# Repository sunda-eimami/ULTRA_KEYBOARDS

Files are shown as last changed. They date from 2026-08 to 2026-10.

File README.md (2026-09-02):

# first — 44キー分割無線キーボード (Ergogen → KiCad)

片側 22 キー（メイン 3行×6列 ＋ 親指 4キー）、Kailh Choc v2 ホットスワップ、
**Seeed XIAO nRF52840 Plus** の分割無線キーボード。`config.yaml` から Ergogen で
左右 2 枚の KiCad PCB を自動生成し、Freerouting による自動配線・DRC・ガーバー生成まで済んでいます。

| 全 44 キー配置 | 配線済み PCB (左/右) |
| --- | --- |
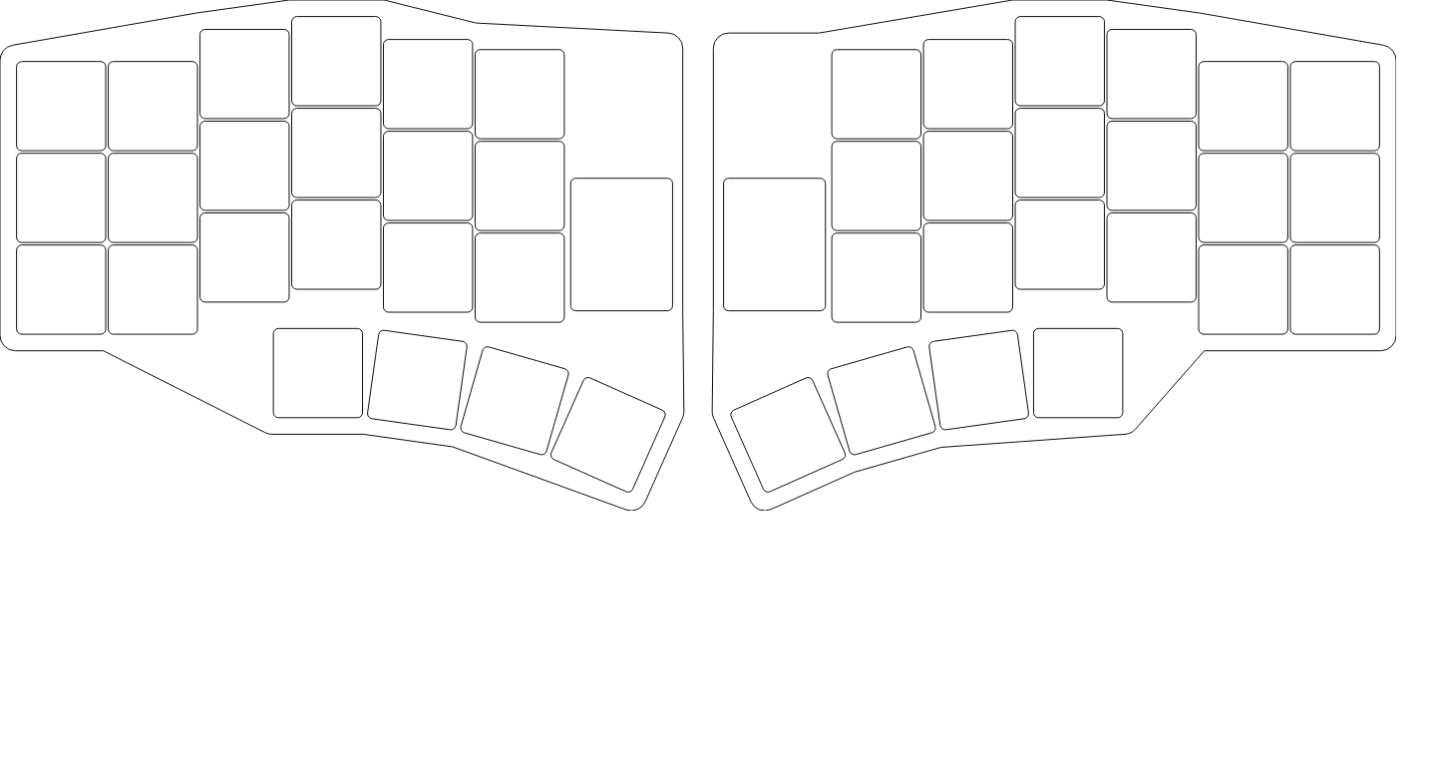
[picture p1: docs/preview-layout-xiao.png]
layout
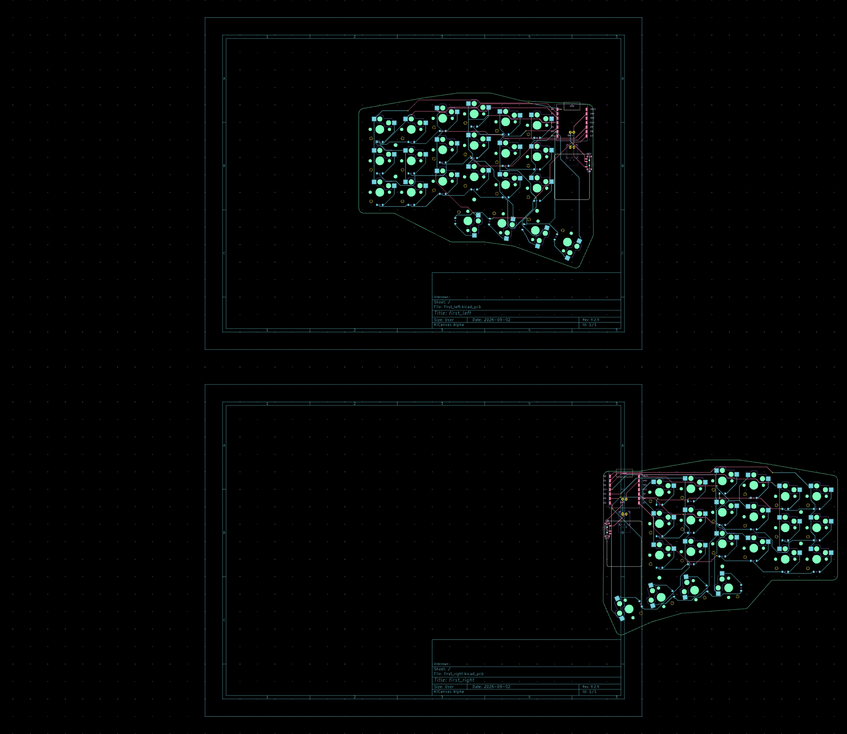
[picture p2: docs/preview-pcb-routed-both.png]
routed
|  |  |

## 状態 (2026-09-02)

- `kicad/first_left.kicad_pcb` / `kicad/first_right.kicad_pcb` — **配線済み・DRC 違反 0・未配線 0**
- `gerbers/first_left.zip` / `gerbers/first_right.zip` — **発注用ガーバー**（JLCPCB 等にそのままアップロード可）

## 使い方

```sh
npm install          # ergogen をローカルにインストール
npm run build        # = ergogen . --clean   → output/ に未配線 PCB を再生成
npm run build:svg    # 外形 SVG も出力
```

> **注意**: `output/` はビルドのたびに完全に上書きされます。配線済みデータは `kicad/`、
> 発注データは `gerbers/` にあり、これらはビルドでは消えません。config を変更したら
> 「`npm run build` → `output/pcbs/*.kicad_pcb` を `kicad/` にコピー → 再ルーティング」が必要です。

## ディレクトリ構成

```
.
├── config.yaml              Ergogen 設定 = 回路の一次ソース (キー配置・外形・ネット定義)
├── footprints/
│   ├── ceoloide/            ceoloide/ergogen-footprints (Choc, ダイオード, JST, 電源SW 等) ※CC BY-NC-SA 4.0
│   └── local/mcu_xiao_nrf52840_plus.js   XIAO nRF52840 Plus (Seeed 公式 KiCad データの座標から作成)
├── output/                  Ergogen 生成物 (未配線。ビルドごとに上書き)
├── kicad/                   配線済み PCB (Freerouting + 手修正、DRC クリーン)
├── gerbers/                 発注用ガーバー zip
└── docs/                    プレビュー画像
```

## 設計メモ

- **配列**: 列は外側から `outer, pinky, ring, middle, index, inner`、行は下から `bottom, home, top`。
  Columnar stagger は pinky 基準で ring +6.3 / middle +8.8 / index +4.3 / inner +2.3 mm。
  親指 4 キーは `rotate: -90`、半径 140mm の円弧上に 8° ピッチで扇状配置。
- **左右別基板**: XIAO は USB・リセットボタンが上面にあるためリバーシブル化できず、
  左手用 (`first_left`) と右手用 (`first_right`) を別々に生成・配線しています。
- **実装面**: スイッチソケット・ダイオード = 裏面 / XIAO・JST・電源スイッチ = 表面。
  XIAO は castellated パッドで表面に直付け。バッテリー (502030) は MCU 下の「ベイ」裏面。
- **ピン割当 (ZMK: `&xiao_d n`)**
  | 用途 | ピン |
  |---|---|
  | 列 outer→inner | D0 D1 D2 D3 D4 D5 |
  | 親指 t1→t4 | D2 D3 D4 D5 (列を流用) |
  | 行 top / home / bottom / thumb | D9 / D8 / D7 / D6 |
  | 電源 | JST(BAT_P) → 電源SW → VBAT (モジュール裏パッド、基板のスルーホール経由で半田付け) |
  | リセット | XIAO 本体ボタン (1回=リセット、素早く2回=ブートローダ) |
  | 空き | D10 (+ Plus 裏面の D11〜D19) |
- **ダイオード**: 1N4148W (SOD-123)、col2row。帯マーク (カソード) が行ネット側。
- **マウントホール**: M2 NPTH ×4/枚。

## 発注 (JLCPCB の例)

1. [jlcpcb.com](https://jlcpcb.com) で `gerbers/first_left.zip` をアップロード → 2層 / 1.6mm / 1oz / HASL でそのまま注文 (最低5枚)
2. `first_right.zip` も同様に注文 (別設計扱い)
3. 部品: Choc v2 スイッチ×44、Choc ソケット×44、1N4148W×44+予備、XIAO nRF52840 Plus×2、
   JST PH 2P×2、電源SW (Alps SSSS811101)×2、502030 LiPo×2

## メンテナンスの流れ

回路図ファイル (.kicad_sch) は存在しません。**`config.yaml` が回路図に相当する一次ソース**で、
接続定義 (from/to) はすべてそこに書かれています。回路を変更するときは config を編集して再生成し、
Freerouting で再ルーティングします (このリポジトリの履歴と配線図ドキュメントを参照)。

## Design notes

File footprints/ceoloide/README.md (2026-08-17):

# @ceoloide's ergogen PCB footprints

> [!WARNING]
> These footprints have only been partially tested and are still under active development. Use them at your own risk.

1. [How to use these footprints in Ergogen](#how-to-use-these-footprints-in-ergogen)
1. [Installation](#installation)
    1. [How to add the footprints as a local git submodule](#how-to-add-the-footprints-as-a-local-git-submodule)
    1. [How to add the footprints as a GitHub Codespaces git submodule](#how-to-add-the-footprints-as-a-github-codespaces-git-submodule)
    1. [How to use the footprints in your ergogen config](#how-to-use-the-footprints-in-your-ergogen-config)
    1. [How to clone your ergogen repo](#how-to-clone-your-ergogen-repo)
    1. [How to update footprints dependencies](#how-to-update-footprints-dependencies)
    1. [How to remove footprints dependencies](#how-to-remove-footprints-dependencies)
1. [How to design or modify ergogen footprints](#how-to-design-or-modify-ergogen-footprints)
1. [Licenses and recognition](#licenses-and-recognition)

## How to use these footprints in Ergogen

> [!WARNING]
> These footprints have been upgraded to KiCad 8 and are only compatible with Ergogen v4.1.0 and above. Make sure to set the `template: kicad8` option in each PCB definition:

```yaml
meta:
  engine: 4.1.0 # Min Ergogen version for KiCad 8 footprints
[...]
pcbs:
  main_pcb:
    template: kicad8 # Required, since footprints are KiCad 8 only
    outlines:
      [...]
    footprints:
      [...]
```

> [!NOTE]
> You can directly use these custom footprints in the experimental GUI at [ergogen.ceoloide.com](https://ergogen.ceoloide.com). Just refer to them as `ceoloide/[footprint_filename]`, for example: `ceoloide/switch_mx`.

Using custom footprints with a local Ergogen setup is relatively straightforward. You can follow the steps outlined in [this amazing guide](https://flatfootfox.com/ergogen-part4-footprints-cases/) if you want an easy tutorial.

If you are already comfortable running Ergogen locally, you just need to:

1. rename your Ergogen YAML file to `config.yaml`,
1. create a `footprints` folder alongside it
1. clone this repo into the `footprints` folder using a folder name of your choice (see instructions below)
1. now run Ergogen by passing a folder instead of a YAML file, for example `ergogen .`

## Installation

### How to add the footprints as a local git submodule

> [!WARNING]
> If you are using GitHub Codespaces, skip the following instructions and go to the next section.

If you have git setup on your local environment with SSH credentials, you can add the library as a
git submodule. To use custom footprint, ergogen requires them to be located under a folder named
`footprints` placed alongside a `config.yaml` file containing the board definition.

Assuming the above files are located at `./ergogen` from the git folder root, then you can use this
command to add the footprints into a `ceoloide` folder in the right location:

```bash
git submodule add git@github.com:ceoloide/ergogen-footprints.git ergogen/footprints/ceoloide
```

Note that you can customize `ceoloide` to be whatever name you choose. Just make sure to refer to the custom
name in your YAML file.

### How to add the footprints as a GitHub Codespaces git submodule

Due to the limitations on how GitHub Codespaces handle submodules, use this command instead of the one above:

```bash
git submodule add https://github.com/ceoloide/ergogen-footprints.git ergogen/footprints/ceoloide
```

### How to use the footprints in your ergogen config

Assuming you used `ergogen/footprints/ceoloide` as the destination folder for the submodule, you will be able
to refer to any footprint contained in that folder as `ceoloide/[footprint_filename]`, which would look something like this:

```yaml
meta:
  engine: 4.1.0 # Min Ergogen version for KiCad 8 footprints
[...]
pcbs:
  your_keyboard:
    template: kicad8 # Required, since footprints are KiCad 8 only
    outlines:
      [...]
    footprints:
      nice_nano:
        what: ceoloide/switch_mx
        [...]
```

### How to clone your ergogen repo

Users who clone your ergogen repo, must also include the submodule. So you should instruct them to clone with `--recursive` mode:

```bash
git clone --recursive git@github.com:your-user/your-keyboard.git
```

Alternative they can init and update the submodules in a repo that was already cloned without the `--recursive` argument:

```bash
git submodule update --init --recursive --remote
```

### How to update footprints dependencies

When you add a submodule, it won't automatically be updated, meaning that you will maintain files as long as you don't take specific actions. This is great to avoid having to deal with unforseen changes in the source.

Should you however want to update your footprint dependencies, you can run the following command:

```bash
git submodule update --recursive --remote
```

This will fetch and checkout the latest commits in the source repo and pull the files so they are available.

Be aware that you will need to commit the submodule update change, or it will revert with a subsequent pull. To do so you can run these commands:

```bash
# First add the updated submodule to the staged files
git add ergogen/footprints/ceoloide
# Then commit the staged files to persist the update
git commit -m "Update footprint submodule"
```

### How to remove footprints dependencies

If you do not longer need the footprint submodule and want to remove it from your repository, you can simply run this command:

```bash
git rm ergogen/footprints/ceoloide
```

This will update the `.gitmodules` file to remove the submodule reference and remove the submodule directory. Make sure to commit and push the
change for it to be persisted and propagated, or it will revert with a subsequent pull:

```bash
git commit -m "Remove footprint submodule"
```

## How to design or modify ergogen footprints

[@infused-kim](https://github.com/infused-kim) wrote a [guide on how to convert KiCad footprints to ergogen](https://www.notion.so/nilnil/Convert-Kicad-Footprint-to-Ergogen-8340ce87ad554c69af4e3f92bc9a0898?pvs=4), which
has been extensively used to create original ergogen footprints in this repository.

## Licenses

All original footprints and those copied from [@MrZealot](https://github.com/mrzealot), [@TildeWill](https://github.com/tildewill), and [@virginia2244](https://github.com/virginia2244) are licensed under [MIT License][mit]. I also extensively used and modified footprints created by [@infused-kim](https://github.com/infused-kim), which are licensed under [Creative Commons Attribution-NonCommercial-ShareAlike 4.0 International License][cc-by-nc-sa].

[][cc-by-nc-sa]

### What does the CC BY-NC-SA 4.0 license mean for your projects?

Because some footprints carry the **Creative Commons Attribution-NonCommercial-ShareAlike 4.0 (CC BY-NC-SA 4.0)** license, there are often questions about what you can and cannot do. 

> [!WARNING]
> I am not a lawyer, and this does not constitute formal legal advice. Below is my informed understanding on how this license practically applies to your keyboard projects.

#### 1. You CAN manufacture and sell the physical PCBs

Creative Commons licenses govern copyright, which protects *digital files and creative expression*, not functional physical hardware. Once you export Gerbers and send them to a fab (like JLCPCB or PCBWay), the resulting physical circuit board is a functional object and is no longer restricted by the CC copyright. You are legally free to commission these boards and sell the manufactured PCBs on your store.

* *Exception:* If a footprint contains separable artistic elements (like decorative silkscreen art), that art remains copyrighted even on the physical board. However, none of the footprints in this repository contain qualifying silkscreen art.

#### 2. You CANNOT sell or close-source the digital files

Your KiCad `.kicad_pcb` files, the generated Gerbers, and the Ergogen config files that use these footprints *are* subject to the copyright license. You cannot sell these digital files. If you share your modified design files or Gerbers with others, you **must** release them under the exact same CC BY-NC-SA 4.0 license and provide attribution.

#### 3. The Spirit of the License

While the license legally permits the sale of the physical, functional boards, applying a NonCommercial license in the open-source hardware community is often used to signal: *"Please don't manufacture and sell my designs for profit."* While you are legally allowed to sell the physical boards, please keep the community spirit in mind.

## Inspiration and recognition

All of the work I've done wouldn't have been possible without the inspiration or direct reference to the work done by:

- [@foostan](https://github.com/foostan) for the original [Corne keyboard](https://github.com/foostan/crkbd)
- [@flatfootfox](https://github.com/flatfootfox) for the [Ergogen v4 introductory articles](https://flatfootfox.com/ergogen-introduction/)
- [@infused-kim](https://github.com/infused-kim) for the [amazing work done with the footprints](https://github.com/infused-kim/kb_ergogen_fp) I ~stole from~ got inspired by
- [@MrZealot](https://github.com/mrzealot) / [@ergogen](https://github.com/ergogen) for the [amazing tool](https://github.com/ergogen/ergogen) and [amazing community](https://discord.gg/Tj2TUaUW)
- [@virginia2244](https://github.com/virginia2244) for the [incredible work on MCU footprints](https://github.com/Virginia2244/ergogen_footprints)
- [@benvallack](https://github.com/benvallack) for the [great video content on YouTube](https://www.youtube.com/watch?v=UKfeJrRIcxw) and getting me started on the Ergogen journey

[mit]: https://opensource.org/license/mit/
[cc-by-nc-sa]: http://creativecommons.org/licenses/by-nc-sa/4.0/
[cc-by-nc-sa-image]: https://licensebuttons.net/l/by-nc-sa/4.0/88x31.png

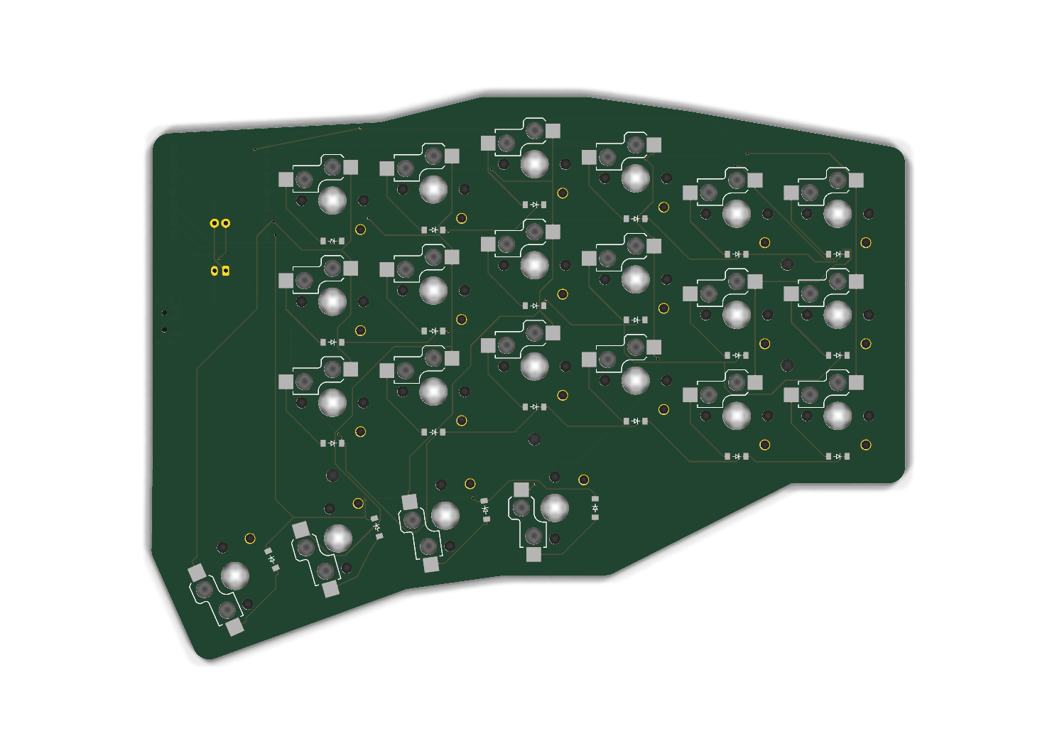
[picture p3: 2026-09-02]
docs/render3d-left-bottom.png

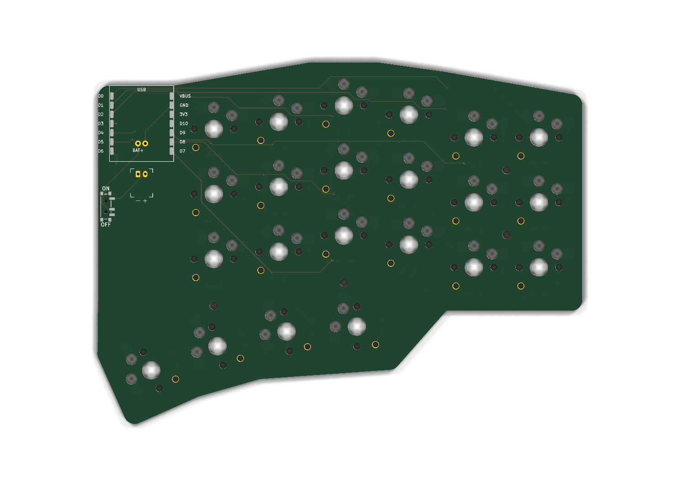
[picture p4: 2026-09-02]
docs/render3d-right-top.png

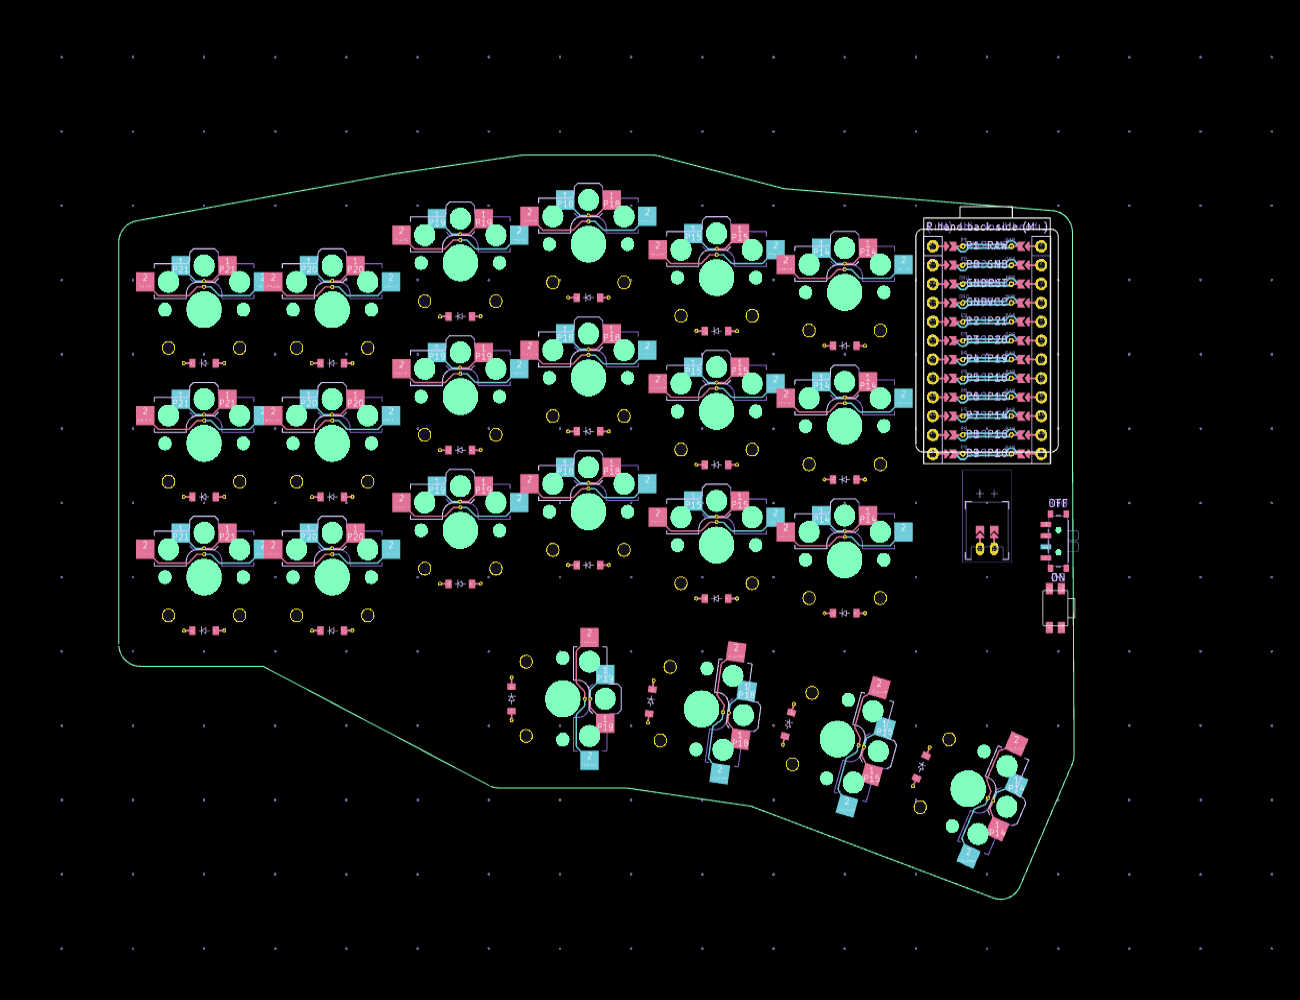
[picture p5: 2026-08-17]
docs/preview-pcb-kicanvas.png

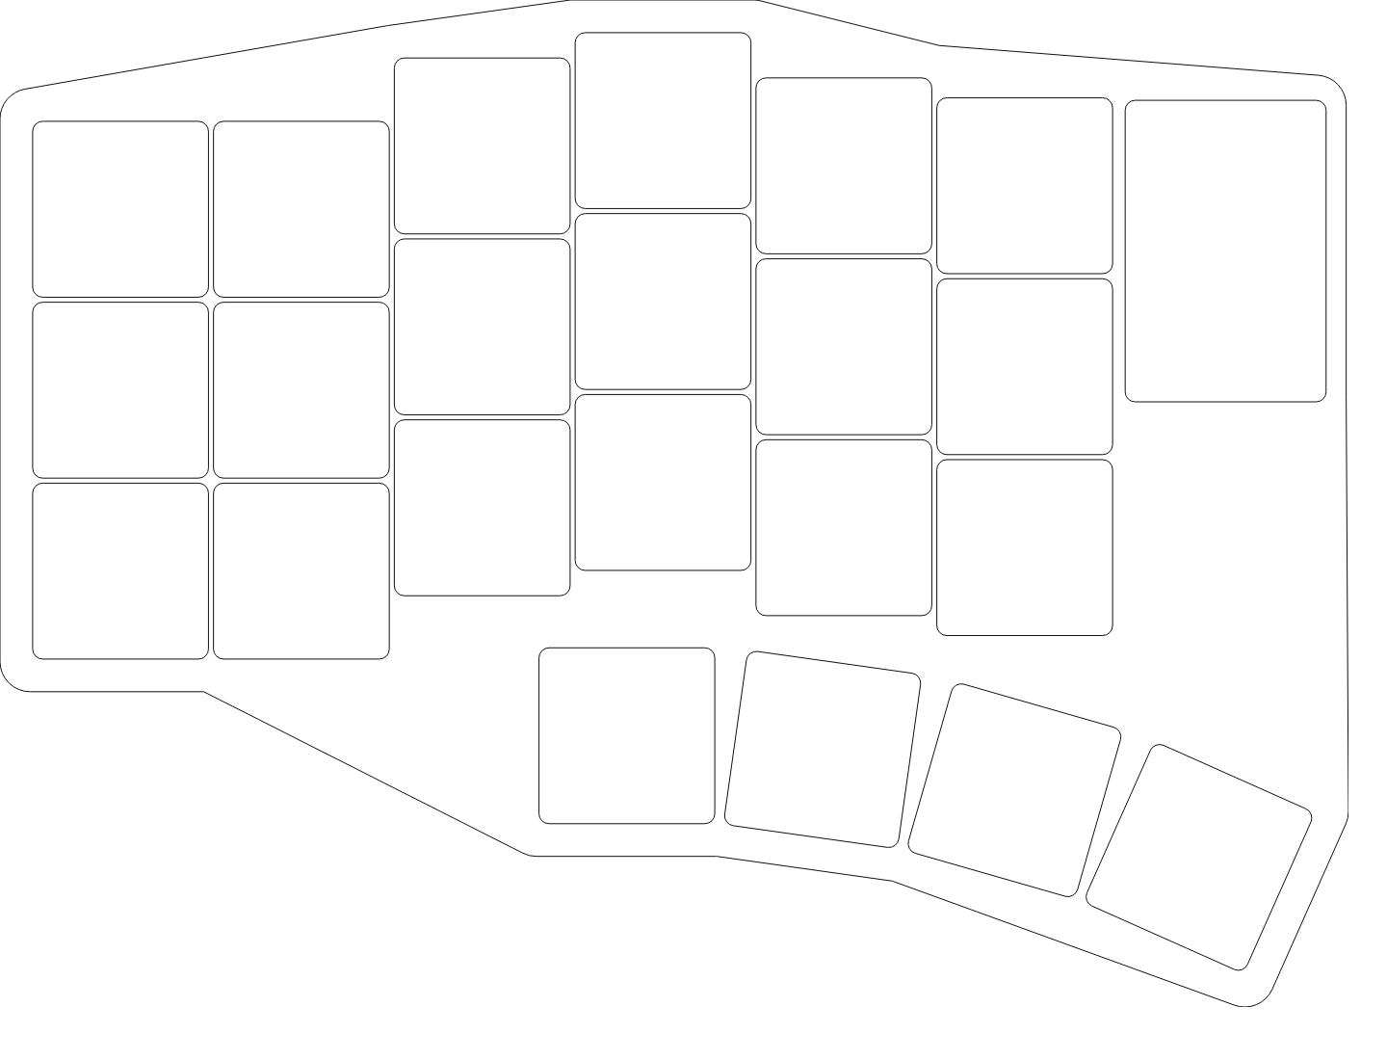
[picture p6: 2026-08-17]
docs/preview-left-outline.png

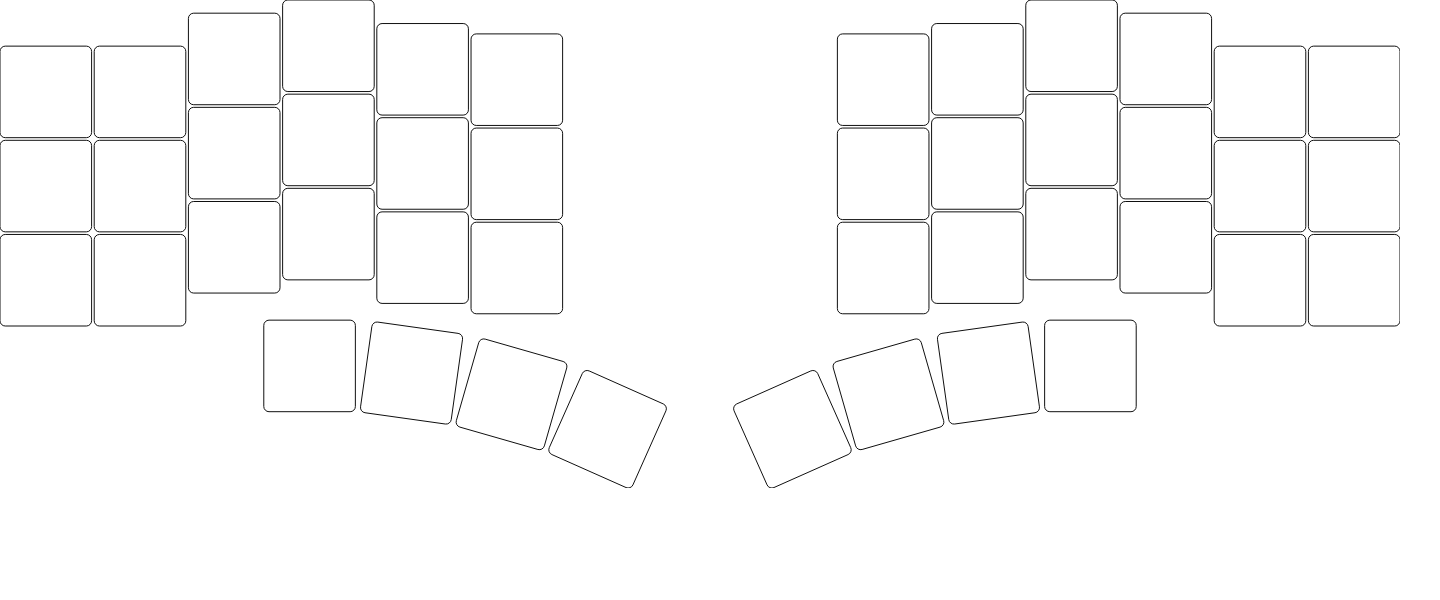
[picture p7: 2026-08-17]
docs/preview-layout-44keys.png

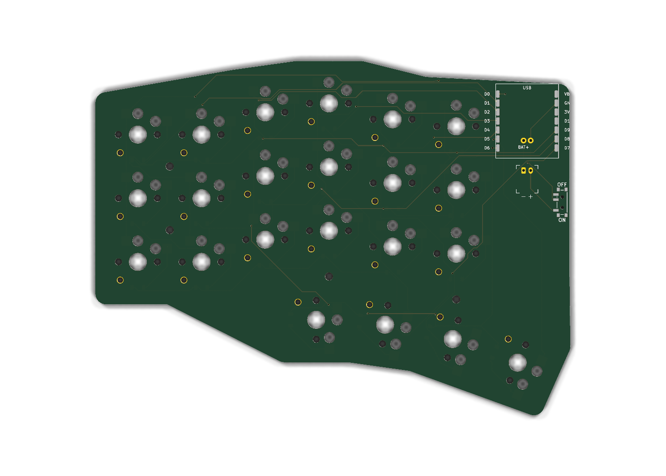
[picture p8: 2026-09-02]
docs/render3d-left-top.png

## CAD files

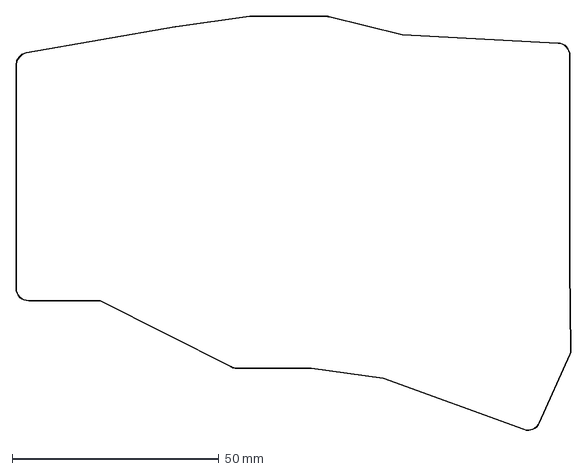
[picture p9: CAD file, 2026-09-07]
cad/board_left.dxf
134.2 x 100.5 mm

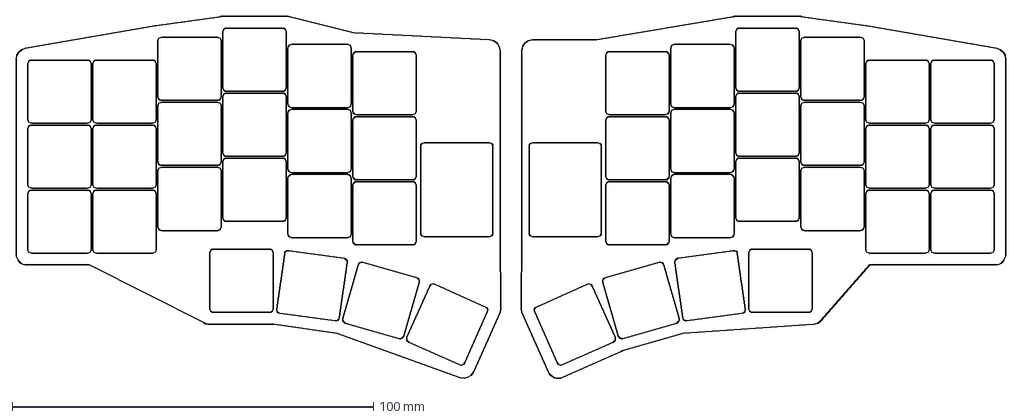
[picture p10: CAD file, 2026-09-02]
output/outlines/preview.dxf
274.0 x 100.5 mm

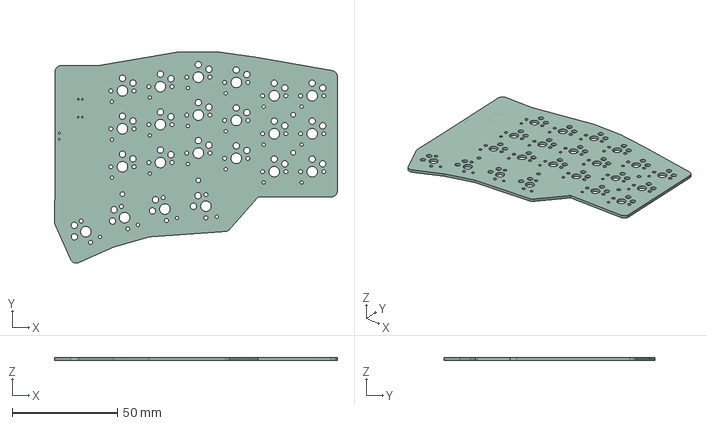
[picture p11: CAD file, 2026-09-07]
cad/first_right.step
134.2 x 100.2 x 1.51 mm

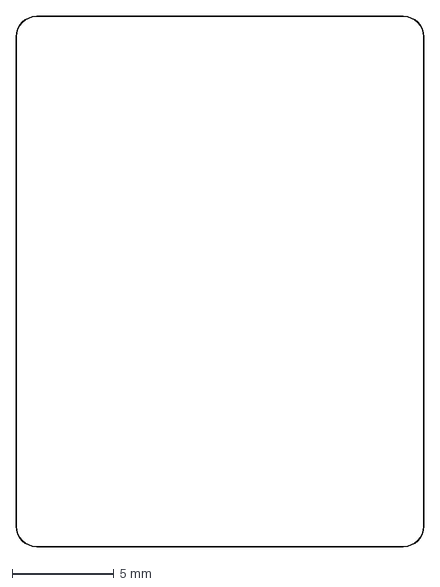
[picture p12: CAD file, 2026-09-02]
output/outlines/battery_right.dxf
20.0 x 26.0 mm

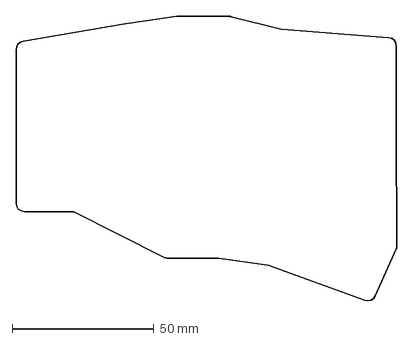
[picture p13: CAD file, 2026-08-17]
output/outlines/board.dxf
134.2 x 100.5 mm

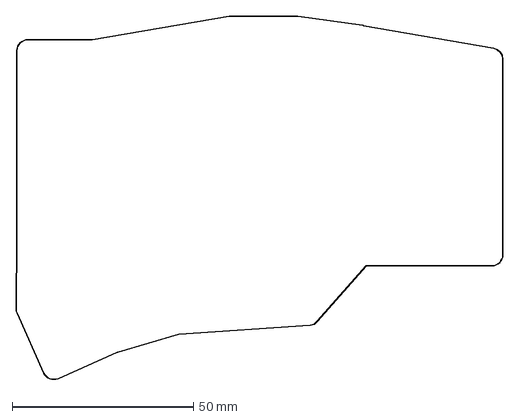
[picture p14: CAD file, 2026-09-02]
cad/board_right.dxf
134.2 x 100.3 mm

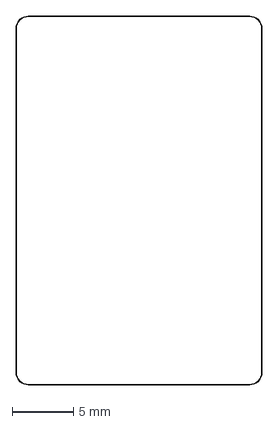
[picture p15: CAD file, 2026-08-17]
output/outlines/battery.dxf
20.0 x 30.0 mm

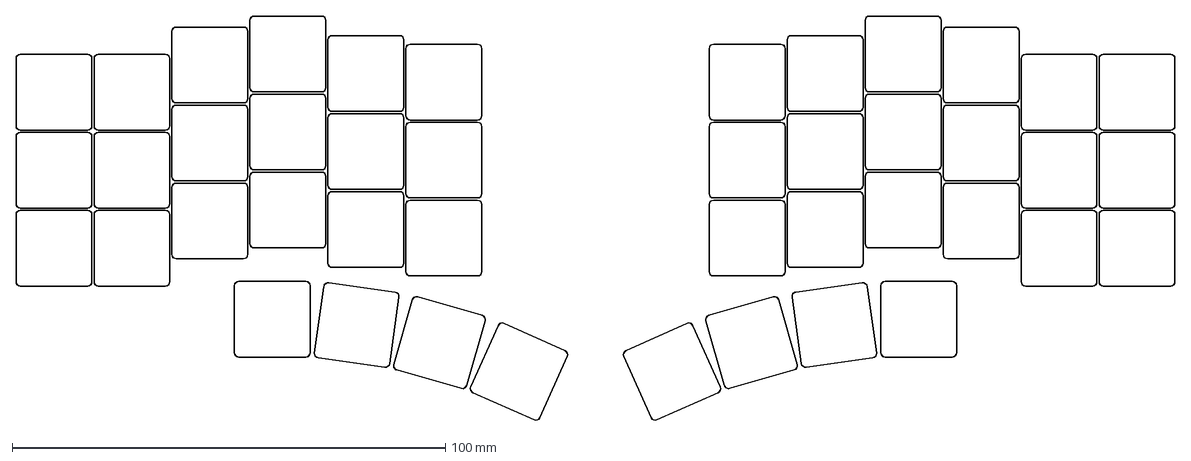
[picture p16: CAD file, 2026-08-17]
output/outlines/keys.dxf
267.5 x 93.4 mm

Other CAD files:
cad/first_left.step

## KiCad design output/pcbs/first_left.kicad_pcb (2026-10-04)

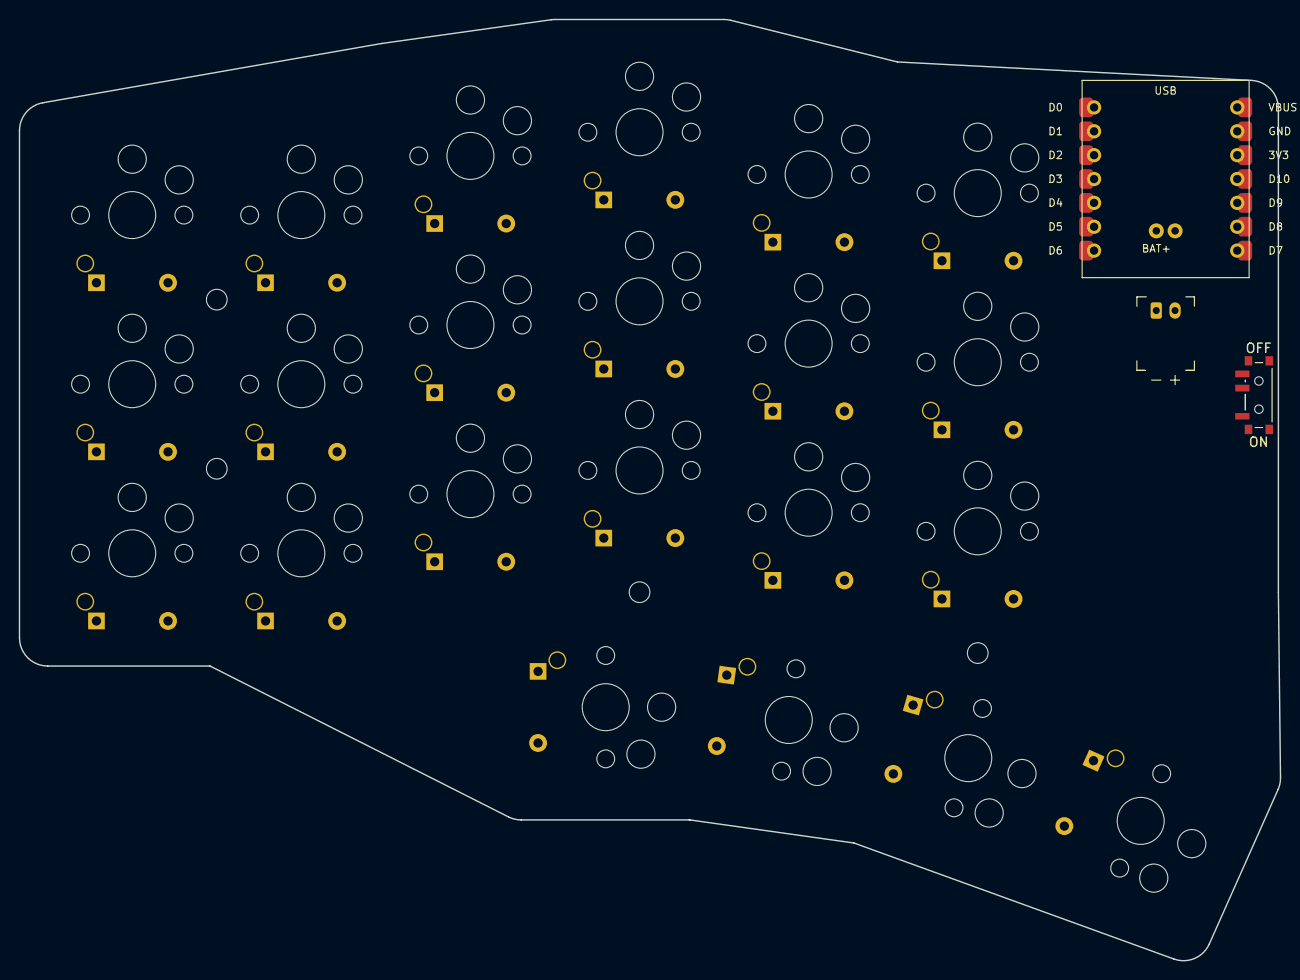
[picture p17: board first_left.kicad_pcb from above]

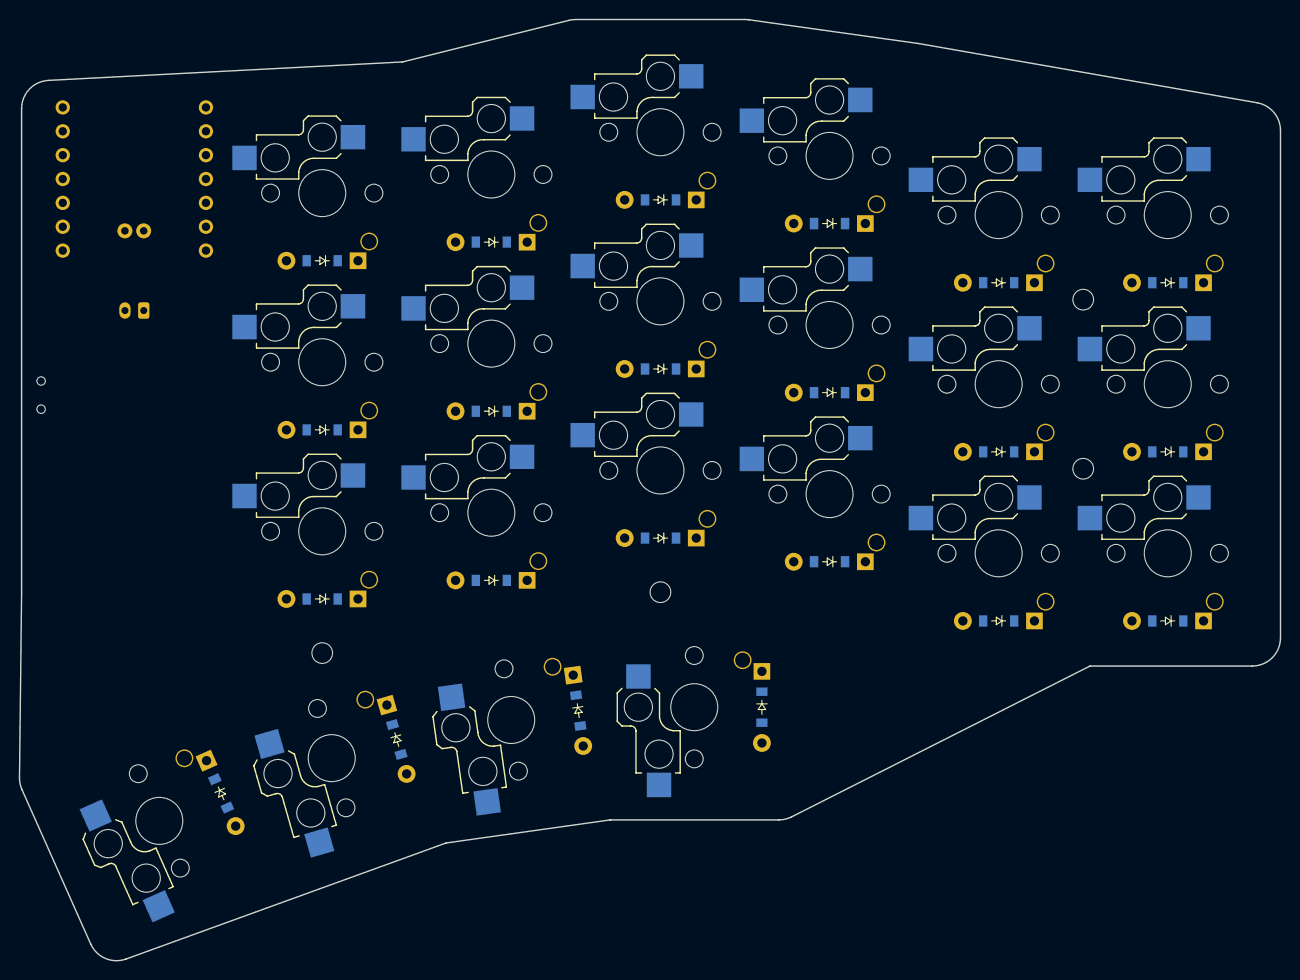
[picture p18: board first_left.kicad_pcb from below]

Board: 2 copper layers, 134.2 x 100.2 mm, 51 parts (44 on the bottom side), 35 nets, no tracks yet.

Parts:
D1, D2, D3, D4, D5, D6, D7, D8, D9, D10, D11, D12, D13, D14, D15, D16, D17, D18, D19, D20, D21, D22: diode_tht_sod123
JST1: battery_connector_jst_ph_2
MCU1: mcu_xiao_nrf52840_plus
MH1, MH2, MH3, MH4: mounting_hole_npth
PWR1: power_switch_smd_side
S1, S2, S3, S4, S5, S6, S7, S8, S9, S10, S11, S12, S13, S14, S15, S16, S17, S18, S19, S20, S21, S22: switch_choc_v1_v2

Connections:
BAT_P: JST1.2, PWR1.1
D0: MCU1.1, S1.1, S2.1, S3.1
D1: MCU1.2, S4.1, S5.1, S6.1
D2: MCU1.3, S7.1, S8.1, S9.1, S19.1
D3: MCU1.4, S10.1, S11.1, S12.1, S20.1
D4: MCU1.5, S13.1, S14.1, S15.1, S21.1
D5: MCU1.6, S16.1, S17.1, S18.1, S22.1
D6: D19.1, D20.1, D21.1, D22.1, MCU1.7
D7: D1.1, D4.1, D7.1, D10.1, D13.1, D16.1, MCU1.14
D8: D2.1, D5.1, D8.1, D11.1, D14.1, D17.1, MCU1.13
D9: D3.1, D6.1, D9.1, D12.1, D15.1, D18.1, MCU1.12
GND: JST1.1, MCU1.9, MCU1.29
VBAT: MCU1.28, PWR1.2
index_bottom: D13.2, S13.2
index_home: D14.2, S14.2
index_top: D15.2, S15.2
inner_bottom: D16.2, S16.2
inner_home: D17.2, S17.2
inner_top: D18.2, S18.2
middle_bottom: D10.2, S10.2
middle_home: D11.2, S11.2
middle_top: D12.2, S12.2
outer_bottom: D1.2, S1.2
outer_home: D2.2, S2.2
outer_top: D3.2, S3.2
pinky_bottom: D4.2, S4.2
pinky_home: D5.2, S5.2
pinky_top: D6.2, S6.2
ring_bottom: D7.2, S7.2
ring_home: D8.2, S8.2
ring_top: D9.2, S9.2
t1_thumb: D19.2, S19.2
t2_thumb: D20.2, S20.2
t3_thumb: D21.2, S21.2
t4_thumb: D22.2, S22.2

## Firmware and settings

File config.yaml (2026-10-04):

# =============================================================================
#  "first" — 44キー(片側22キー) 分割無線キーボード  Ergogen 設定  (XIAO 版)
# -----------------------------------------------------------------------------
#  - 片側: メイン 3行 x 6列 (outer/pinky/ring/middle/index/inner) + 親指 4キー
#  - Gallium v2 風 Columnar Staggered (薬指・中指を上げ、人差し指・小指を下げる)
#  - Kailh Choc v2 (PG1353) + Choc ホットスワップソケット (裏面)
#  - MCU: XIAO nRF52840 Plus (表面・DIP式: 貫通穴に流し込みハンダ) / ダイオード: SMD/THT両対応
#  - 502030 LiPo は MCU 下の「ベイ」領域の裏面に配置 (ガイド矩形を Dwgs.User に出力)
#  - 基板は左右で別設計 (first_left / first_right)。XIAO は USB とリセットボタンが
#    上面にあるためリバーシブル1枚基板にできない。
#
#  ピン割当 (ZMK: &xiao_d n):
#    列 outer..inner = D0 D1 D2 D3 D4 D5 / 親指 t1..t4 = D2 D3 D4 D5 (列を流用)
#    行 top=D9 home=D8 bottom=D7 thumb=D6
#    電源 JST(BAT_P) -> 電源SW -> VBAT (モジュール裏パッド) / リセットは本体ボタン
#
#  ビルド: npm run build  (= npx ergogen . --clean)
#  フットプリント: footprints/ceoloide/ (CC BY-NC-SA 4.0),
#                  footprints/local/mcu_xiao_nrf52840_plus.js (Seeed公式座標より)
# =============================================================================

meta:
  engine: 4.1.0
  name: first
  version: 0.3.0

# ---------------------------------------------------------------- 単位・変数
units:
  kx: 18               # キーピッチ X (mm)
  ky: 18               # キーピッチ Y (mm)
  px: 3                # 基板外形の余白 (キー外周からエッジまで)
  mcu_w: 18            # XIAO 幅 17.78mm + マージン
  mcu_h: 21            # XIAO 長さ (USB 突出 1.2mm は除く)
  bat_w: 20            # 502030 LiPo 幅
  bat_h: 30            # 502030 LiPo 長さ (厚み 5mm)
  bat_gap: 6           # プレビューでの左右基板の間隔
  thumb_splay: -8      # 親指キー1個あたりの扇状回転角 (時計回りが負)
  thumb_radius: 140    # 親指の弧の半径 (回転中心はキー中心から thumb_radius 下)

# ---------------------------------------------------------------- キー配置
points:
  key:
    spread: kx
    padding: ky
    width: kx
    height: ky

  # 右手側ポイント (mirror_*) の生成。右手基板 first_right はこちらを使う
  mirror:
    ref: mcu
    distance: mcu_w + 2px + bat_gap

  zones:
    # ------------------------------------------------------------ メインエリア
    matrix:
      anchor:
        shift: [100, -100]   # KiCad 上で座標が正になるようにオフセット
      columns:
        outer:                       # 装飾キー用 (小指の外側)
          key:
            column_net: D0
        pinky:
          key:
            stagger: 0
            column_net: D1
        ring:                        # 薬指: 大きく上げる
          key:
            stagger: 0.35ky
            column_net: D2
        middle:                      # 中指: 最も高い位置
          key:
            stagger: 0.14ky
            column_net: D3
        index:                       # 人差し指: 中指より下げる
          key:
            stagger: -0.25ky
            column_net: D4
        inner:                       # 人差し指の内側: さらに少し下げる
          key:
            stagger: -0.11ky
            column_net: D5
      rows:
        bottom:
          row_net: D7
        home:
          row_net: D8
        top:
          row_net: D9

    # ------------------------------------------------------------ 親指エリア
    thumb:
      anchor:
        ref: matrix_index_bottom
        shift: [-1.2kx, -1.15ky]
      key:
        rotate: -90              # 親指の可動域に直交させる
        row_net: D6              # 親指行
      columns:
        # t2 以降は thumb_radius 下の共通中心まわりに thumb_splay ずつ回転 → 真円弧
        t1:
          key:
            column_net: D2
        t2:
          key:
            spread: 0
            splay: thumb_splay
            origin: [0, -thumb_radius]
            column_net: D3
        t3:
          key:
            spread: 0
            splay: thumb_splay
            origin: [0, -thumb_radius]
            column_net: D4
        t4:
          key:
            spread: 0
            splay: thumb_splay
            origin: [0, -thumb_radius]
            column_net: D5
      rows:
        thumb:

    # ------------------------------------------------------------ MCU (XIAO nRF52840 Plus)
    # inner 列の右隣。モジュール上端 (USB) が基板上端とほぼ面一になる位置
    mcu:
      anchor:
        ref: matrix_inner_top
        shift: [0.5kx + 2 + 0.5mcu_w, 1.5]
      key:
        width: mcu_w
        height: mcu_h - 6    # 基板端がモジュール上端に来るよう外形計算上は短く扱う

    # ------------------------------------------------------------ 電源ベイ (バッテリー+JST+電源SW)
    # MCU 直下に外形を下へ広げるための領域。ポイント名は "batt"
    batt:
      anchor:
        ref: mcu
        shift: [0, -29]
      key:
        width: mcu_w
        height: bat_h
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

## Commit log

2026-09-02 Switch MCU to XIAO nRF52840 Plus; dedicated L/R boards, routed & gerber-ready
    - Replace nice!nano v2 with Seeed XIAO nRF52840 Plus (custom ergogen
    footprint from Seeed official KiCad data; VBAT/GND as PTH for
    back-side soldering; no RST pad on Plus -> onboard button)
    - Split into two dedicated PCBs (first_left / first_right) since the
    XIAO cannot be used on a reversible board (USB/reset on top face)
    - New pin map: cols D0-D5, rows D9/D8/D7/D6, thumbs reuse D2-D5,
    JST(BAT_P) -> power switch -> VBAT; add M2 NPTH mounting holes x4
    - Route both boards (freerouting 1.9 via pcbnew DSN/SES pipeline,
    manual fixes for D0 edge clearance and t3_thumb); DRC clean 0/0
    - Add routed boards under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
    [battery_right.dxf, board_right.dxf, first.kicad_pcb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]
2026-09-07 Add case-design exports (STEP models, outline DXF)
    - cad/first_left.step, cad/first_right.step: exact 3D models of the
    routed boards (outline + all holes) for Fusion case design
    - cad/board_left.dxf, cad/board_right.dxf: 2D edge outlines
    - restore gerbers/first_right/ (accidentally dragged to repo root)
    Claude-Session: https://claude.ai/code/session_01U2bmDd4aXzFym29z7uVdNh
    [board_left.dxf, board_right.dxf, first_left.step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]
2026-10-04 Move ZMK config to standard repo-root layout
    build-user-config.yml runs west from the repo root, so a nested
    zmk/config workspace breaks west update. Use the standard config/ +
    build.yaml layout instead.
    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
    [first_left.kicad_pcb, first_right.kicad_pcb]
2026-10-04 Use xiao_ble//zmk board id (ZMK Zephyr 4.1 / HWMv2)
    ZMK main moved to Zephyr 4.1 in Dec 2025; seeeduino_xiao_ble was
    renamed to xiao_ble with the mandatory //zmk variant.
    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
2026-10-04 Add local ZMK build script (Docker)
    scripts/build-firmware.sh builds first_left/first_right UF2s with the
    official zmkfirmware/zmk-build-arm:stable image. ZMK + Zephyr sources
    are cached in the zmk-first-workspace volume, so rebuilds take seconds.
    Output goes to firmware/ (gitignored).
    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
